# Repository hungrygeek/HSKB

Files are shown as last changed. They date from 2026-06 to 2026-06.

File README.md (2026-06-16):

# HSKB – Happy Sabi KeyBoard



> **Fork notice:** This is a community fork of the original **HSKB (Happy Sabi Keyboard)** by Dev01-D. The original upstream repository is no longer available, so this copy is maintained at <https://github.com/hungrygeek/HSKB> under the project's MIT license. All original credits below are retained.

## About the HSKB

The HSKB is a custom mechanical keyboard inspired by the minimalist layout and functionality of the HHKB (Happy Hacking Keyboard). It reflects a philosophy of simplicity, precision, and personal expression.

Designed with a true HHKB layout, the HSKB features a 6u spacebar and an integrated plate design that supports both plate-mounted and PCB-mounted stabilizers. Drawing inspiration from the legendary HHKB and driven by a passion for thoughtful design and community collaboration, this project has been a personal journey—learning new software, iterating through multiple prototypes, and spending approximately three months refining every detail.

I am excited to share the HSKB with the open-source community and hope it inspires others to create and contribute. This project would not have been possible without the support and inspiration from the keyboard community.

## Why Choose the HSKB?

Many keyboards with a similar HHKB-inspired layout are often positioned as luxury items, carrying a high price tag and limited customization options. The HSKB offers a more affordable entry point without sacrificing quality or flexibility. Its open-source nature means you can modify and adapt it to suit your preferences—whether it's changing the key mapping, adjusting the stabilizers, or customizing the case.

The HSKB provides a unique balance of cost-efficiency and personalization. It's an excellent option for enthusiasts looking to explore the HHKB layout without breaking the bank. Whether you're new to mechanical keyboards or an experienced hobbyist, the HSKB offers a rewarding, hands-on experience while remaining accessible and adaptable.

## Unity Switch & Andy's Man Club

This project is also inspired by **Matty's Unity switch**, created in support of **Andy's Man Club**, a mental health charity promoting open conversations and community support. As part of this commitment, one of the five initial HSKBs will be donated to a charity raffle to raise funds for this meaningful cause.

If you use or modify this project, please consider supporting **Andy's Man Club** or a mental health charity in your community.

- https://andysmanclub.co.uk/
- https://thoccexchange.com/

## Features

- **Minimalist Layout** – Inspired by the HHKB design
- **Custom PCB & Case Files** – Fully customizable and open-source (thanks to **TheVoid** for helping with this)
- **Community-Driven** – Built with love, feedback, and support

## What's Included

- [PCB design files (KiCad)](https://github.com/hungrygeek/HSKB/tree/main/PCB%20Files)
- [Case design files (STEP, STL for 3D printing)](https://github.com/hungrygeek/HSKB/tree/main/HSKB%20STL)
- [HS Firmware configuration (QMK/VIA-compatible)](https://github.com/hungrygeek/HSKB/tree/main/PCB%20Files/VoidHHKB-Hotswap/firmware)
- [Solder Firmware configuration (QMK/VIA-compatible)](https://github.com/hungrygeek/HSKB/tree/main/PCB%20Files/VoidHHKB-Solder/firmware)

## Getting Started

1. **Clone the repository:**
    ```bash
    git clone https://github.com/hungrygeek/HSKB.git
    cd HSKB
    ```

2. **Explore the design files:**
   - PCB files: Located in the `/pcb` directory
   - Case files: Located in the `/case` directory
   - Firmware: Instructions in `/firmware` for flashing QMK/VIA

3. **Manufacture & Build:**
   - Order your PCB from your preferred manufacturer
   - Print the case using the provided STL files
   - Assemble the board using the included BOM (Bill of Materials)

## Contributing

Contributions and improvements are welcome! Feel free to submit issues, pull requests, or ideas to enhance the HSKB.

1. Fork the repository
2. Create a new branch
3. Submit a pull request

## License

This project is released under the **MIT License** – you're free to use, modify, and share it. Please credit this repository if you share your own builds.

## Support

If you build your own HSKB, I would love to see it! Share your creations and thoughts.

Consider donating to **Andy's Man Club** or any mental health charity to help continue supporting important community work.

Thank you for being a part of the journey.

**Happy building!**

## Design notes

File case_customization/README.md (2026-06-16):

# Case customization workspace

Tooling and renders used to produce the rounded-edge + **SSKB**-engraved case variants
(the finals live in `../HSKB STL/`). Everything here was generated with **Blender**
(headless, Cycles CPU — Workbench/EEVEE don't render headless on macOS).

## Layout
- `scripts/` — Blender Python scripts (rounding, engraving, measuring, rendering)
- `renders/` — preview / verification renders (incl. the hero shots `hero2_*`)
- `wip_stl/` — intermediate STLs (the print-ready finals are in `../HSKB STL/`)

## Key scripts
| Script | Purpose |
|---|---|
| `finalize_bevel.py` | Orientation-aware selective edge rounding (`hi`/`lo` side, auto height-axis) |
| `engrave_text.py` | Engrave text into the top face via a boolean difference + manifold cleanup |
| `measure_holes.py` | Find screw holes / standoffs and report diameters |
| `screw_profile.py` | Profile a screw column (counterbore / pilot / depth) |
| `hero_render.py` | Assembled top+bottom hero render (metallic purple) |
| `render_case.py`, `compare_radius.py`, `find_text.py` | Inspection / comparison renders |

## Example
```bash
B="/Applications/Blender.app/Contents/MacOS/Blender"
# round the top's top edge at 2.5 mm:
"$B" --background --python scripts/finalize_bevel.py -- \
  "../HSKB STL/HHKB v13 v1_top.stl" out_top.stl prefix 2.5 6 hi
```

## Final settings used
- Edge rounding: **2.5 mm** fillet (top: high side; bottom: base/low side)
- Engraving: **"SSKB"**, 0.4 mm deep, **front-right** border (user's right = −X, spacebar edge = +Y)
- Both final meshes verified watertight (0 non-manifold edges).

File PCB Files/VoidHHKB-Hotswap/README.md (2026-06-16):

# VoidHHKB-Hotswap





## Ordering from JLCPCB

1) Head to the [JLCPCB order page](https://cart.jlcpcb.com/quote).

2) Upload the `VoidHHKB-Hotswap.zip` file in `production/`.

3) Set the quantity of the PCBs you want made.

4) Set your desired PCB parameters. Here are some suggested parameters: (Everything else can be kept at their default)

- PCB Color: **Purple**
- Surface Finish: **ENIG**
- Remove Order Number: **Yes**   

5) Enable the PCB Assembly option at the bottom, and set the following parameters:

- PCBA Type: **Standard**
- Assembly Side: **Bottom**

6) Press `Confirm` at the bottom or `NEXT` on the right to get to the next page.

7) Click `NEXT` to get to the Bill of Materials tab.

8) Click `Add BOM File` and select the `bom.csv` file in `production/`.

9) Click `Add CPL File` and select the `positions.csv` file in `production/`. Click `Process BOM & CPL` to proceed.

10) You should be presented with a list of all the components and quantities needed. Double check there are no missing components. If there are, you will have to find substitute components for it. Click `NEXT` to proceed.

11) You should be presented with a view of the PCB and its components. You will most likely need to rotate the Hotswap sockets manually. Click `NEXT` to proceed.

12) You should see a breakdown of the price for the PCBs you want to order. Select `Keyboard - HS Code 847330` under `Office Appliance Accessories` for the Product Description.

13) Save to cart, and pay for it!

## Flashing Firmware

1) Install and launch [QMK Toolbox](https://qmk.fm/toolbox)

2) Connect PCB via USB. Hold down reset button to enter bootloader

3) Under 'Local file' open firmware/void_voidhhkb_via.bin. Everything else can be left as default (MCU is STM32F072 / STM32 DFU — QMK Toolbox auto-detects it in bootloader mode)

4) Click Flash!

5) Unplug and plug in again to complete set up

## Using VIA

Temp instructions until I get around to merging files into QMK repo...
1) To edit keymap in via open web page and select 'Design' on the top ribbon

2) Click 'Load Draft Definition' and load '/firmware/voidhhkb/via.json'

## Build your own firmware

- Files have been included under 'firmware' if you want to build the bin files yourself.
- This is fairly trivial to do by following the [QMK Tutorial](https://docs.qmk.fm/newbs)

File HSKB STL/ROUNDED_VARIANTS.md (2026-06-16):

# Rounded / customized case variants

Edge-rounded variants of the case. **The originals are unchanged** — these are additional files.

| File | Based on | Changes |
|---|---|---|
| `HHKB v13 v1_top_rounded_SSKB.stl` | `HHKB v13 v1_top.stl` | Top outer edge + corners rounded (**2.5 mm** fillet). **"SSKB" lightly engraved** (0.4 mm deep) on the front-right border, matching the original logo placement. |
| `HHKB v13 v1_bottom_rounded.stl` | `HHKB v13 v1_bottom.stl` | Base (desk-facing) outer edge rounded (**2.5 mm** fillet); top mating rim left sharp so it still seats on the top piece. |

Notes:
- Switch/stabilizer cutouts and all mating surfaces are untouched — switch fit and case assembly are preserved.
- Both meshes verified **watertight / manifold** (0 non-manifold edges) → print-ready.
- A 2.5 mm round needs **no supports**; print as you would the originals.
- Suggested material: **silk PLA** (matches the original look) or **PETG** (tougher). Generated with Blender.

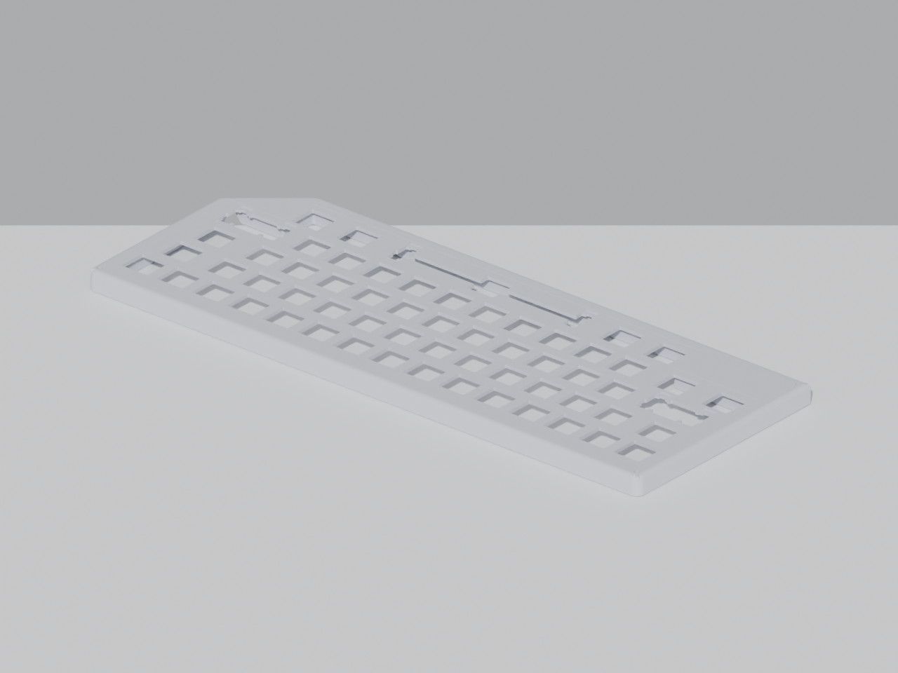
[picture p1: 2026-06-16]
case_customization/renders/after_25_iso.png

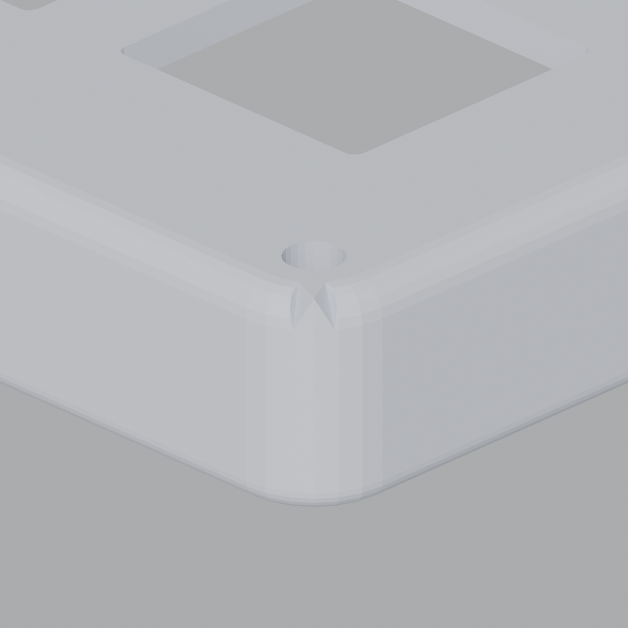
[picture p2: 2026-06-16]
case_customization/renders/macro_15.png

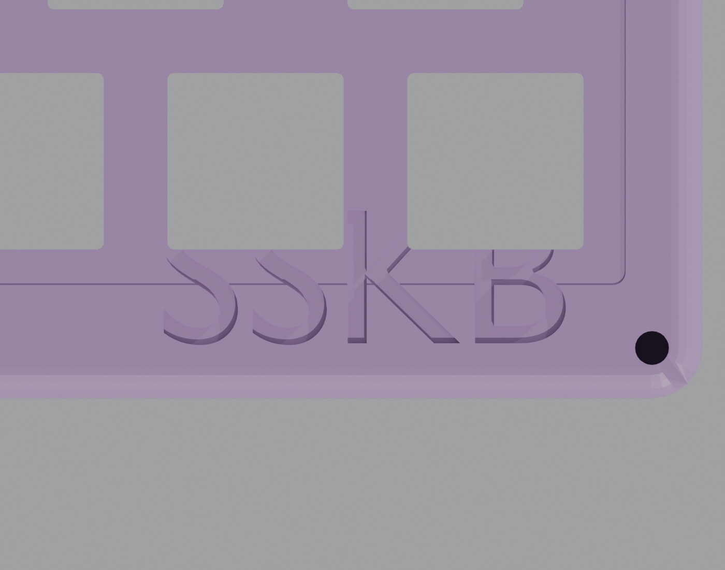
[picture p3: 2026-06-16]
case_customization/renders/engrave_top.png

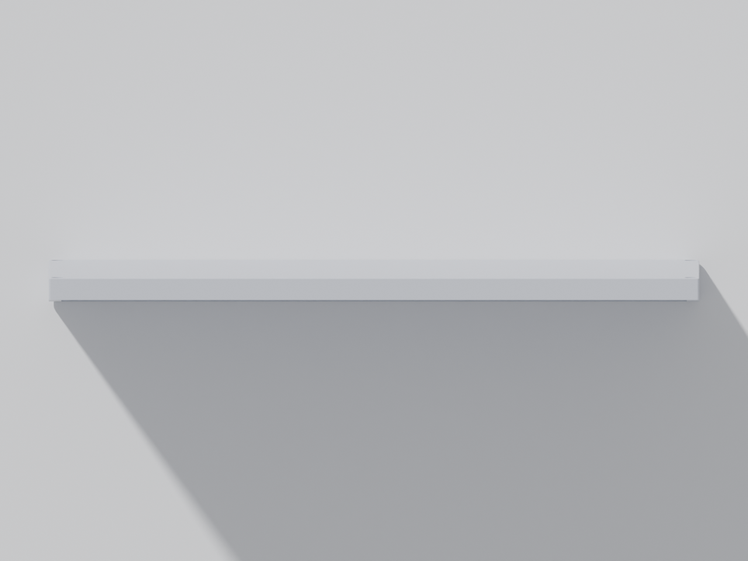
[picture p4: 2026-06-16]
case_customization/renders/bottom_before_top.png

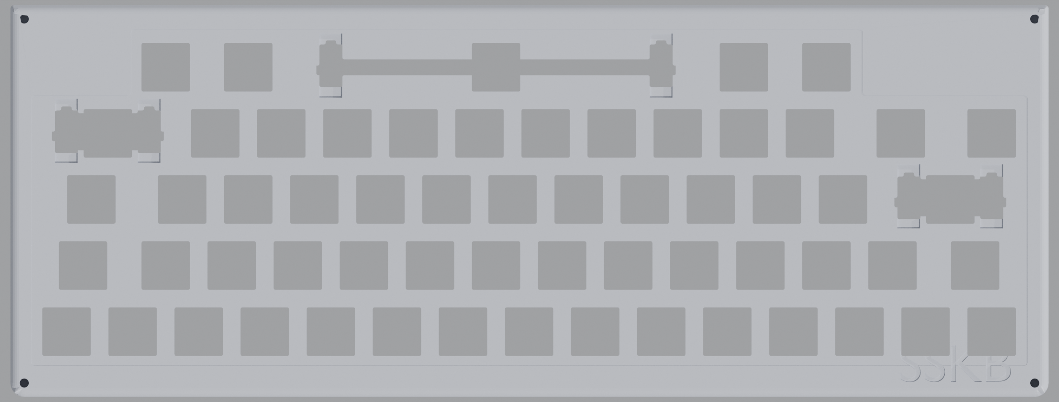
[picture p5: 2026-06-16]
case_customization/renders/diag_topdown.png

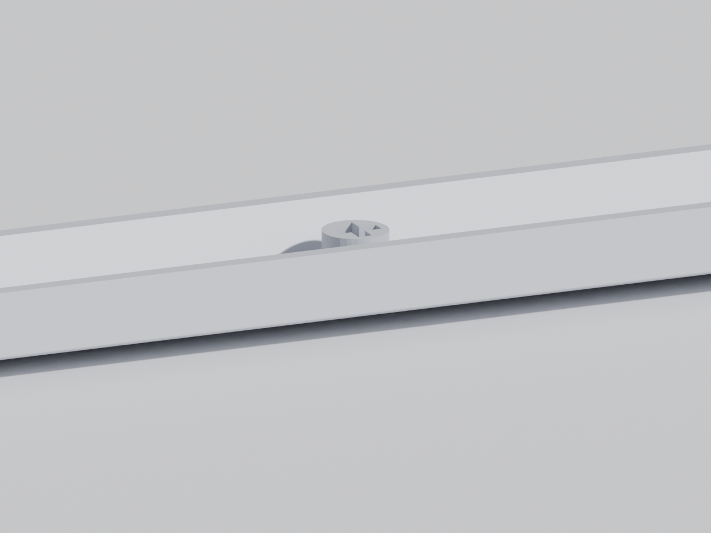
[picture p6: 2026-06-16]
case_customization/renders/spacebar_corner.png

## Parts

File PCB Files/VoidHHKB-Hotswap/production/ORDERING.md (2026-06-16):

# Ordering the VoidHHKB-Hotswap PCB (turnkey)

The files in this folder upload to JLCPCB as-is — every assembly part now has an LCSC number.

## Files
- `VoidHHKB-Hotswap.zip` — Gerbers (upload as the PCB)
- `bom.csv` — assembly BOM (all lines have LCSC #s)
- `positions.csv` — CPL / placement file (143 parts, bottom layer)

## Resolved assembly parts
The original BOM was missing LCSC numbers for two lines; now filled in:
- 60× `1N4148W` diode, SOD-123 → **C81598** (JLC basic part)
- 60× Kailh MX hotswap socket, CPG151101S11 → **C5184526** (extended part — expect a one-time feeder fee)

## JLCPCB settings
- Quantity: **5** (JLC minimum). Assemble **3** (or all 5 — setup/stencil fees dominate, so 5 is barely more).
- Surface finish: **ENIG**. Remove order number: **Yes**.
- **PCB Assembly: ON** → Assembly side **Bottom**, type **Standard**.
- Upload `bom.csv` + `positions.csv` → *Process BOM & CPL*.
- ⚠️ In the placement preview, **rotate the hotswap sockets** if they look mis-oriented.
- Product description: `Keyboard - HS Code 847330`.
- Shipping: **DHL/FedEx/UPS express** for fastest delivery to the US.

MCU is **STM32F072** (STM32 DFU bootloader) — see `../README.md` for flashing.

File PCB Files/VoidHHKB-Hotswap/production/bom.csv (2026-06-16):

Designator | Footprint | Quantity | Value | LCSC Part #
C1, C8 | 0402 | 2 | 4.7uF | C23733
C2, C3, C7, C9 | 0402 | 4 | 100nF | C1525
C4, C5, C6, CR2 | 0402 | 4 | 1uF | C52923
CR1 | 0402 | 1 | 10uF | C15525
D1 | SOT-143 | 1 | PRTR5V0U2X | C2827688
D10, D11, D12, D13, D14, D15, D16, D17, D18, D19, D2, D20, D21, D22, D23, D24, D25, D26, D27, D28, D29, D3, D30, D31, D32, D33, D34, D35, D36, D37, D38, D39, D4, D40, D41, D42, D43, D44, D45, D46, D47, D48, D49, D5, D50, D51, D52, D53, D54, D55, D56, D57, D58, D59, D6, D60, D61, D7, D8, D9 | D_SOD-123 | 60 | 1N4148W | C81598
F1 | 1206 | 1 | 500mA | C69688
MX1, MX10, MX11, MX12, MX13, MX14, MX15, MX17, MX18, MX19, MX2, MX20, MX21, MX22, MX23, MX24, MX25, MX26, MX27, MX28, MX3, MX31, MX32, MX33, MX34, MX35, MX36, MX37, MX38, MX39, MX4, MX40, MX41, MX42, MX43, MX44, MX45, MX46, MX47, MX48, MX49, MX5, MX50, MX51, MX52, MX53, MX55, MX56, MX58, MX6, MX60, MX7, MX8, MX9 | SW_MX_HS_CPG151101S11_1u | 54 | MX_SW_HS | C5184526
MX16, MX29, MX57, MX59 | SW_MX_HS_CPG151101S11_1.5u | 4 | MX_SW_HS | C5184526
MX30, MX54 | SW_MX_HS_CPG151101S11_1.75u | 2 | MX_SW_HS | C5184526
QR1 | SOT-23 | 1 | 2N7002 | C8545
R1, R2 | 0402 | 2 | 5k1 | C25905
RR1 | 0402 | 1 | 33k | C25779
RR2 | 0402 | 1 | 10k | C25744
RR3 | 0402 | 1 | 100k | C25741
SWR1 | SW_SPST_TL3342 | 1 | TS-1187A-B-A-B | C318884
U1 | SOT-23 | 1 | XC6206P332MR | C5446
U2 | LQFP-48_7x7mm_P0.5mm | 1 | STM32F072CBT6 | C81720
USB1 | USB_C_Receptacle_HRO_TYPE-C-31-M-12 | 1 | USB_C_Receptacle_USB2.0_16P | C165948

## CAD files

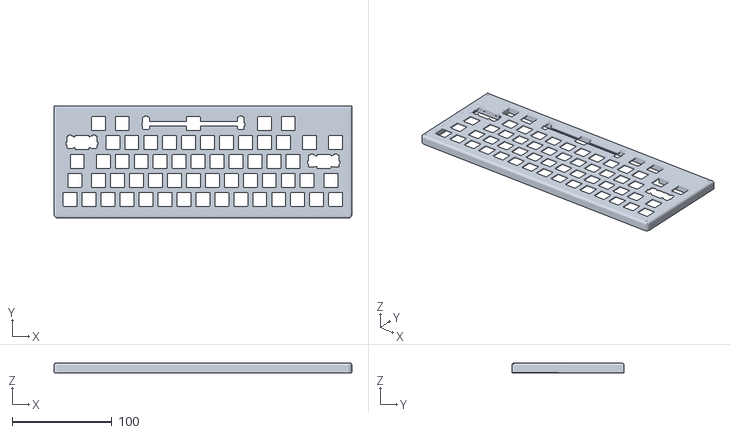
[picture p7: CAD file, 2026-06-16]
case_customization/wip_stl/HHKB_v13_v1_top_rounded_25.stl
299.5 x 113.0 x 10.1

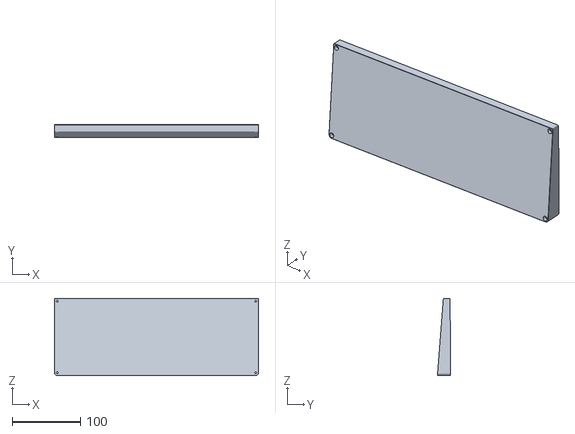
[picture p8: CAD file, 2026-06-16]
case_customization/wip_stl/HHKB_v13_v1_bottom_rounded.stl
299.5 x 19.2 x 113.0

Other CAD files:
HSKB STL/HHKB v13 v1_top_rounded_SSKB.stl
case_customization/wip_stl/HHKB_v13_v1_top_final_v2.stl
case_customization/wip_stl/HHKB_v13_v1_top_final.stl

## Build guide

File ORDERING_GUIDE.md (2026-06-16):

# HSKB / SSKB — Complete JLC Ordering Guide

Everything needed to order the **PCB (JLCPCB)** and the **case (JLC3DP)**, plus the
remaining parts to finish the build.

- **Board:** HHKB-layout 60%, **hotswap MX**, 6u spacebar, STM32F072, QMK/VIA.
- **Case:** 2.5 mm rounded edges + **"SSKB"** lightly engraved, printed in **MJF nylon**.
- All files referenced below are in this repo and are upload-ready.

---

## 0. At a glance

| Item | Vendor | Upload / provide | Approx cost | Lead time |
|---|---|---|---|---|
| PCB (assembled) | **JLCPCB** (jlcpcb.com) | gerber zip + `bom.csv` + `positions.csv` | ~$80–160 | ~1.5–2 wk |
| Case (2 parts) | **JLC3DP** (jlc3dp.com) | 2 × STL | ~$60–150 | ~1–1.5 wk |
| Screws / stabs / cable | Amazon etc. | — | ~$20–40 | 1–2 days |

> JLCPCB and JLC3DP are **separate sites/carts** (same login). Place both around the
> same time; they will likely ship separately.

---

## Part A — PCB from JLCPCB

### Files to provide
All in `PCB Files/VoidHHKB-Hotswap/production/`:

| File | Role |
|---|---|
| `VoidHHKB-Hotswap.zip` | Gerbers — upload as the PCB |
| `bom.csv` | Assembly BOM (turnkey — every part has an LCSC #) |
| `positions.csv` | CPL / placement file (143 parts, bottom side) |

### Step by step
1. **jlcpcb.com** → sign in (free account; first orders often get coupons).
2. **Add gerber file** → upload `VoidHHKB-Hotswap.zip`; wait for the top/bottom preview.
3. **Base PCB options:**
   - PCB Qty: **5** (JLC minimum)
   - Surface finish: **ENIG** *(change from default HASL)*
   - PCB color: **Purple** (or your choice) · Remove order number: **Yes**
   - Leave **1.6 mm / 2-layer / 1 oz** at default
4. **Enable PCB Assembly** →
   - Assembly side: **Bottom**
   - Type: **Standard**
   - PCBA Qty: **3** (or **5** — setup/stencil fees dominate, so spares are cheap)
5. **Upload `bom.csv` + `positions.csv`** → **Process BOM & CPL**. Confirm the column
   mapping (Designator / Comment / Footprint / LCSC Part #).
6. **Parts review:** everything auto-matches. The **hotswap socket (C5184526)** is an
   *extended* part → accept the one-time feeder fee.
7. **Placement review:** ⚠️ **rotate the hotswap sockets** if the preview shows them
   mis-oriented; sanity-check diode / USB-C / STM32 placement.
8. **Customs / product description:** `Keyboard - HS Code 847330`.
9. **Checkout** → shipping: **DHL / FedEx / UPS express** to the Bay Area
   *(not "Global Standard")*.

### Resolved BOM parts (already filled in)
- `1N4148W` diode, SOD-123 → **C81598** (JLC basic part)
- Kailh MX hotswap socket, CPG151101S11 → **C5184526** (extended part)

### After it arrives
- Flash `PCB Files/VoidHHKB-Hotswap/firmware/void_voidhhkb_via.bin` with **QMK Toolbox**.
- **MCU = STM32F072 / STM32 DFU** (hold reset to enter bootloader; QMK Toolbox
  auto-detects it). *Not ATmega — ignore any old README note.*

---

## Part B — Case from JLC3DP

### Files to provide
All in `HSKB STL/` — both watertight, in **millimeters**:

| File | Role |
|---|---|
| `HHKB v13 v1_top_rounded_SSKB.stl` | Top: rounded top edge + "SSKB" engraving |
| `HHKB v13 v1_bottom_rounded.stl` | Bottom: rounded base edge |

### Step by step
1. **jlc3dp.com** → **3D Printing quote** → **Add STL** (upload **both** parts).
2. **Process: MJF** · **Material: PA12 Nylon (grey)** — optional **dyed black** for a
   more premium look.
3. Review the instant **DFM check** (flags any wall < 0.8 mm — the case should pass).
4. **Qty per part:** **1** to validate fit first *(recommended)*, or **3**.
5. **Finish:** standard bead-blasted matte = the frosted look; add dyeing if offered.
6. **Checkout** → express shipping to the Bay Area.

### Why MJF nylon (PA12)
Robust and impact-resistant (not brittle like resin), with a premium uniform
matte/frosted finish and no layer lines. The 299 × 113 mm parts fit the MJF envelope,
and the 0.4 mm SSKB engraving renders cleanly. *(SLA resin was only for translucency,
which you don't need.)*

---

## Part C — Other parts to buy (Amazon, McMaster, etc.)

| Part | Spec | Notes |
|---|---|---|
| **Case screws** | **M2.5 button-head assortment, ~10–22 mm** (self-tapping or machine) | Heads sit on the bottom; they self-tap into the top boss. Buy a kit and use the length that seats flush + bites — avoids a wrong-length re-order. |
| **Stabilizers** | **PCB-mount**: 2× **2u** (for the 2.25u Enter + left Shift) + 1× **6u** spacebar | Board has PCB-mount stab footprints. Confirm the 6u spacebar stab spacing. |
| **Switches** | ~**60 × MX** (3- or 5-pin; 5-pin clips into the plate) | 54×1u + 4×1.5u + 2×1.75u + spacebar |
| **Keycaps** | **HHKB 60% set with a 6u spacebar** | (you have these) |
| **USB-C cable** | data-capable | |

Amazon search that covers size + length in one kit: **"M2.5 button head screw assortment kit"**.

---

## Part D — Build order (to avoid re-iterations)

1. Order the **PCB (5 boards, assemble 3)** + **one case set** first.
2. On arrival: flash firmware → install **PCB-mount stabs** → clip in switches →
   seat PCB in the case → fit **M2.5 screws** (pick the length that seats flush) →
   keycaps.
3. **Validate the full fit on this one unit**, then print the remaining **2 cases**.

> Fitment has been verified against the source files: top↔bottom footprints match
> (299.45 × 113 mm), the 4 corner screw points align within ~0.3 mm, and the case
> customizations (rounding + engraving) did not alter any cutouts, screw holes, or
> mating surfaces. Still, a one-unit test build is the cheapest insurance.

---

## Spec sheet (quick reference)

- **Layout:** HHKB 60%, 6u spacebar · **Switches:** hotswap MX · **MCU:** STM32F072 · **Firmware:** QMK/VIA
- **Case:** top + bottom, 2.5 mm rounded edges, "SSKB" engraved 0.4 mm, **MJF PA12 nylon**
- **Screws:** M2.5 · **Stabs:** PCB-mount (2× 2.25u + 1× 6u)
- **Footprint:** 299 × 113 mm
- **PCB BOM key parts:** diode `C81598`, hotswap socket `C5184526`

---
*See also: `PCB Files/VoidHHKB-Hotswap/production/ORDERING.md` (PCB detail) and
`HSKB STL/ROUNDED_VARIANTS.md` (case STL detail).*

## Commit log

2026-06-16 docs: correct MCU in flashing instructions (STM32F072, not ATmega32U4)
2026-06-16 pcb: fill missing LCSC parts (diode C81598, hotswap socket C5184526) + turnkey ORDERING.md
    [bom.csv]
2026-06-16 case: add 2.5mm rounded-edge variants + SSKB engraving (top & bottom); originals preserved
    [HHKB v13 v1_bottom_rounded.stl, HHKB v13 v1_top_rounded_SSKB.stl]
2026-06-16 docs: add full JLC ordering guide (PCB via JLCPCB + case via JLC3DP) with parts list
2026-06-16 fix: move SSKB engraving to front-right corner (was back-left), matching original HSKB placement
    [HHKB v13 v1_top_rounded_SSKB.stl]
2026-06-16 Add case_customization workspace (Blender scripts, renders, WIP STLs)
    [HHKB_v13_v1_bottom_rounded.stl, HHKB_v13_v1_top_final.stl, HHKB_v13_v1_top_final_v2.stl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]
2026-06-16 fix: SSKB engraving to true front-right (X-max, +180deg) — verified via ray-cast layout map + front-view readability
    [HHKB v13 v1_top_rounded_SSKB.stl]
